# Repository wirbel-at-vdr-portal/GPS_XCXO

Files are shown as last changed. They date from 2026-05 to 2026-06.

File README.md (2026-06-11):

# About
Project goal is a small budget hobbyists GPS disciplined 10MHz XCXO with less than 0.01Hz freq offset at 10MHz using a GPS receiver with 1PPS output.

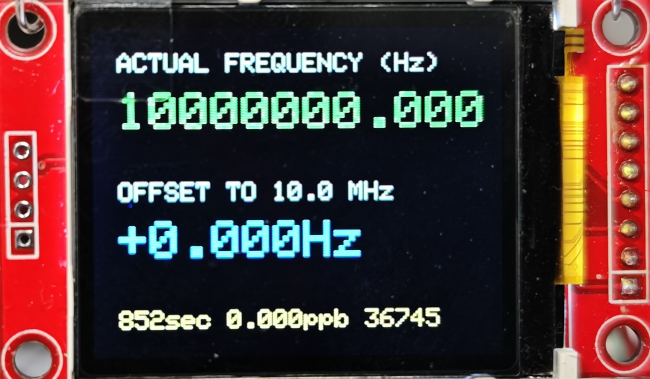
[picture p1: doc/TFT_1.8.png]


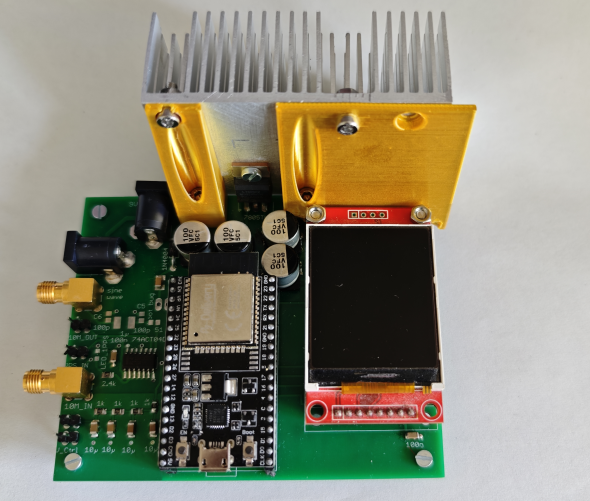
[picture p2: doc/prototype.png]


# Ingredients
- an cheap 10MHz OCXO with 0..4 volts V_control input, which has in it's voltage control range the center freq of 10.000000 MHz and CMOS or TTL output,
  costs at common market places ~15€. I use an CTI OSC5A2B02 OCXO based board. It needs to be modified however, to have a control voltage input instead of a potentiometer.
- an ESP32 devkit C V4, ~12€ (mine was ~8€)
- Arduino IDE with a few libs, 0€, but some efforts in/plus time/research.
- a GPS module with an 1 pulse per second output, in my case
  - Sparkfun GPS-17285 module (Neo-M9N)
  - Sparkfun GPS-14986 antenna
- a few electronic components
- an old 1.8 inch TFT based on St7735, i use the one with the large SD card slot, ~6€
- the PCB, design is here, ~25€ for 5 pieces.
- a 9..12volts DC power supply with ~1amp continously, - no costs. Everybody has such one laying around. Preferred with the 5.5mm 'DC connector', plus is inner.

# How it is working
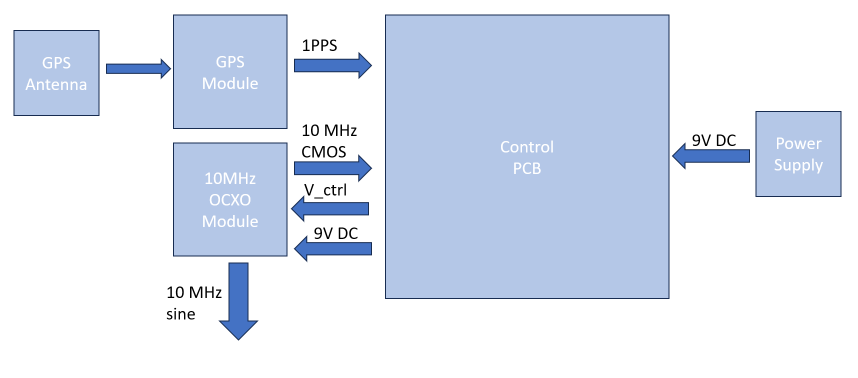
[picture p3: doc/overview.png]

- the 1PPS signal from the GNSS / GPS module triggers an interrupt routine, which resets a counter.
- the 10MHz signal is counted by the ESP32 specific hardware counter PCNT. Every 30000 counts, this counter fires a second ISR to count it's overflows.
  This ISR is called 333 times a second.
- if the gate time is over, we remember the current counter value (0..29999) as 'last_counter' and calculate the number of pulses: pulses = current_counter + overflows * 30000 - last_counter
- now, we can calculate the frequency: frequency = pulses / gate_time
- and the current frequency error in ppb: errorPPB = (measuredFreq - TARGET_FREQ) / (TARGET_FREQ / 1e9)
- as our OCXO is voltage controlled by 0..4volts, we need to generate a control voltage. We generate a 16-bit PWM, again using hardware counters of the ESP32.
- the pwm signal is RC filtered, we need to put a bit effort in this filter. We want more than 120dB frequency suppression for the PWM frequency.
- and finally, we somehow need to map an error in ppb to an PWM value. This job serves a digital filter with a bit brain, the Kalman filter.
- if the OCXO is learned, the program stores from time to time the current state

# Modification of the OCXO board
My OCXO board doesnt have a control voltage input. Instead, the input is wired to a potentiometer. The modified circuit is shown below.

NOTE: the original schematic was not done by me, see doc folder for original.

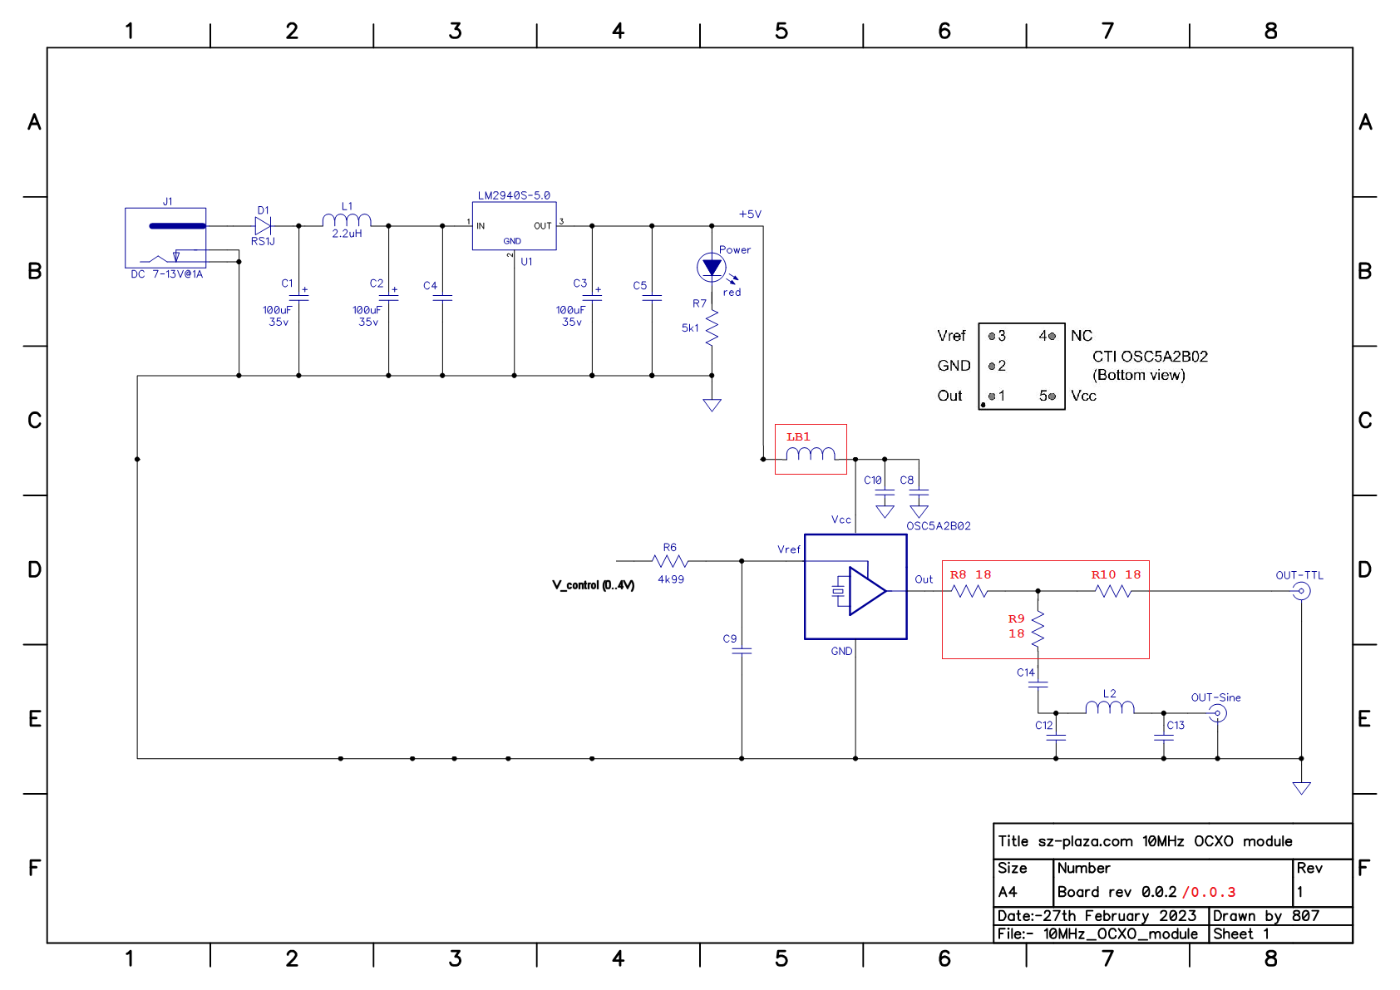
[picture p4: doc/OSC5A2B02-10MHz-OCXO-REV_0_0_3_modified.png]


# Performance
- for my system, which is a very early breadboard-like assembly
- the algorithm needs time to adapt the OCXO, learn it's properties, so it's slow. Don't expect good results in less than two hours.
- there are still plenty of knobs to tune
- we need the OCXO control signal as clean as possible, so shielding and good RC filtering is mandatory.
- TODO
  - improve GPS quality (cheap module)
  - tune code, if GPS loss or invalid values.

| Running hh:mm:ss | abs(FreqOffset), Hz | PWM change 0..65535 | Uncertainty | comment |
| --- | --- | --- | --- | --- |
| 00:00:10 | 2.9 | 4751 | 490.8 | |
| 00:00:20 | 1.8 | 2949 | 947.4 | |
| 00:02:00 | 1.65 | 2703 | 264.0 | |
| 00:03:40 | 0.51 |  836 | 205.7 | |
| 00:12:00 | 0,216 |  354 |  10.7 | |
| 00:28:40 | 0.058 | 95 | 2.65 | |
| 00:45:20 | 0.013 | 21 | 2.31 | |
| 01:02:00 | 0.002 | 3 | 1.9982 | |
| 01:18:40 | 0.040 | 7 | 1.726 | GPS err  |
| 01:18:50 | 0 | 0 | 3.4488 | algo! |
| 01:35:30 | 0.002 | 3 | 1.8489 | recover  |
| 01:52:10 | 0.001 | 2 | 1.3932 | |

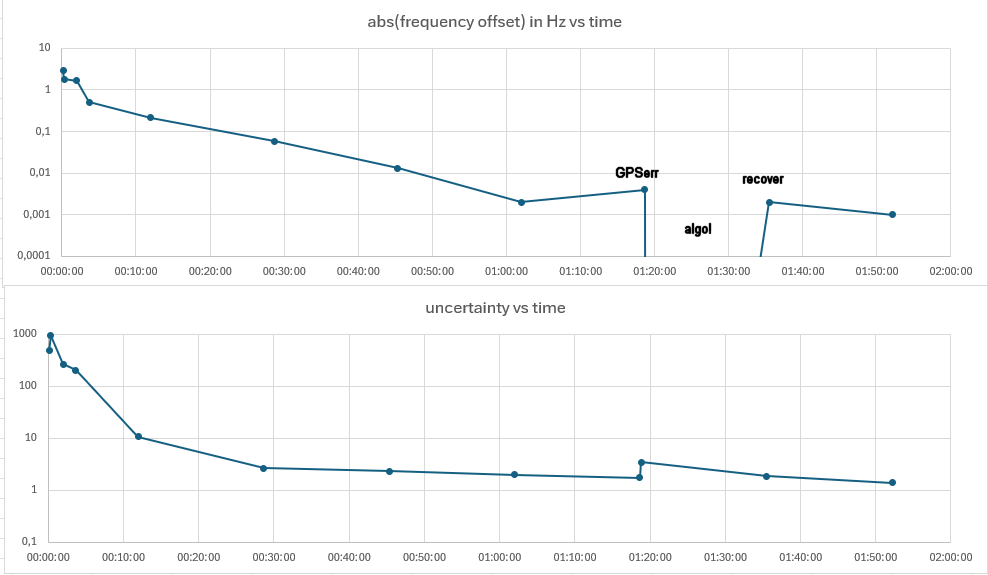
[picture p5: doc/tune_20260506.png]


***NOTE NOTE NOTE:***

***This is work in progress. Everything still changes day by day. Success is optional, this is a fully fun based project.***

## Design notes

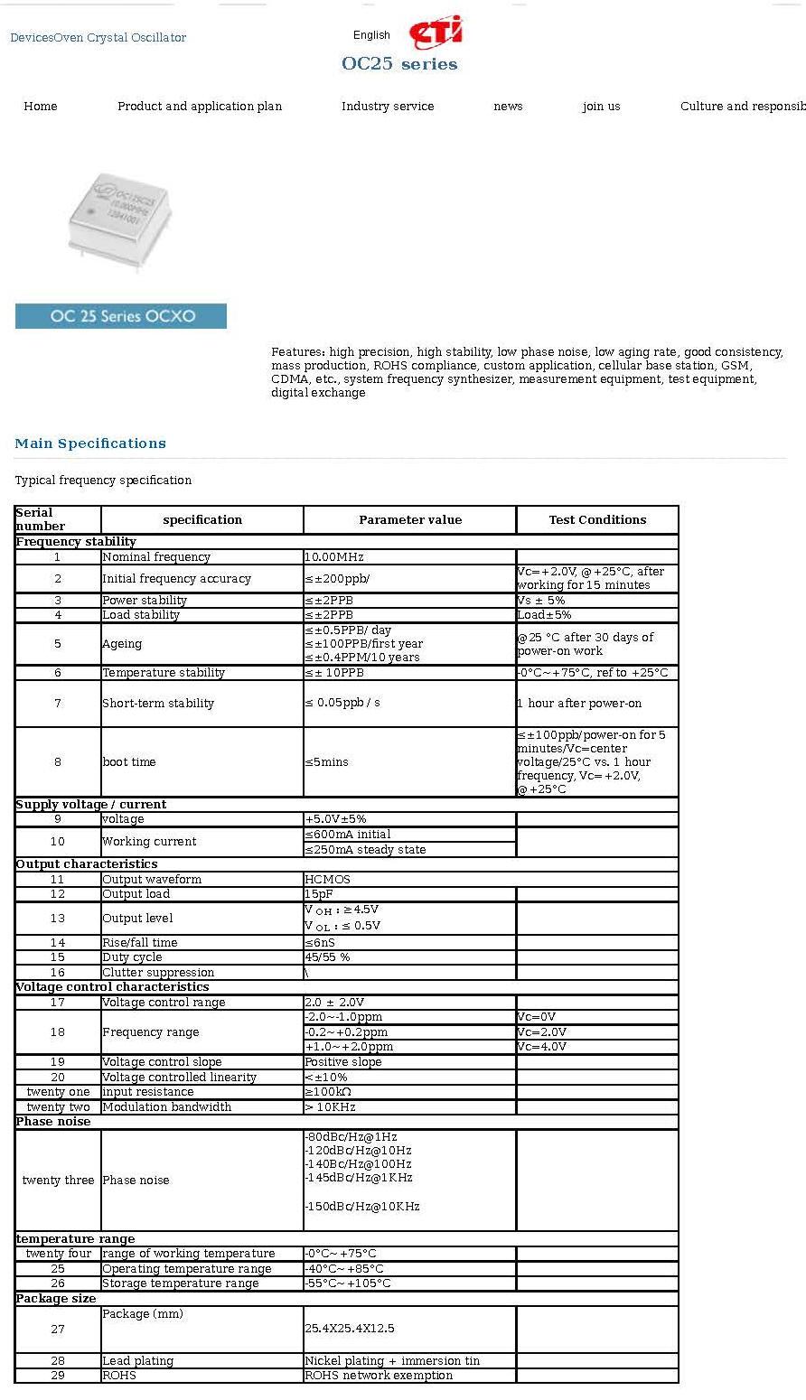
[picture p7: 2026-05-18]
doc/CTI Serie25 VC-OCXO.jpg

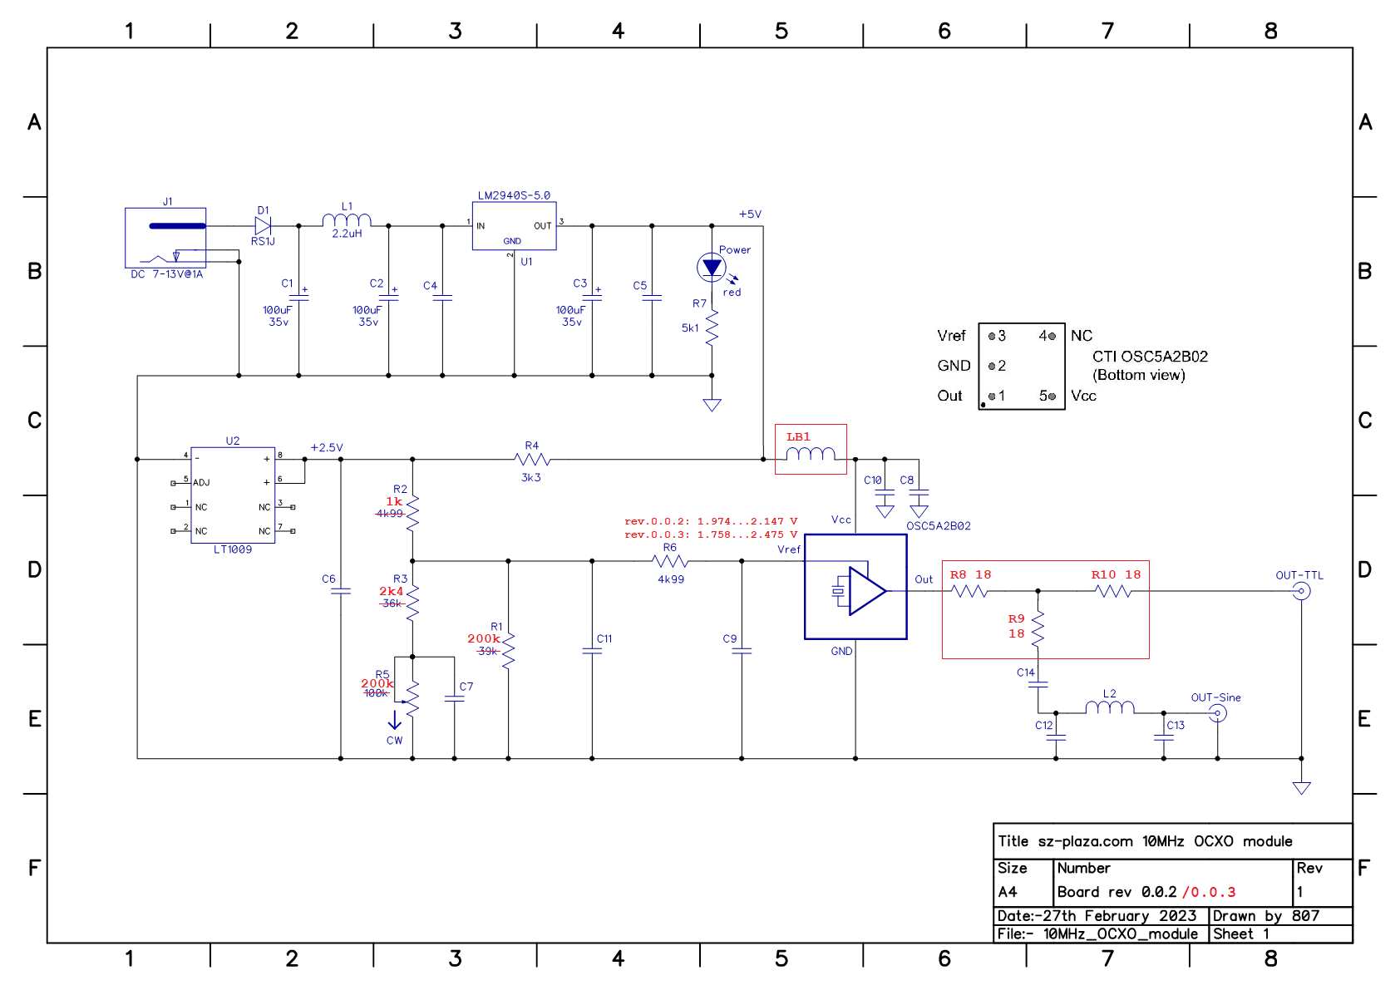
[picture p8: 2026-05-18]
doc/OSC5A2B02-10MHz-OCXO-REV_0_0_3.png

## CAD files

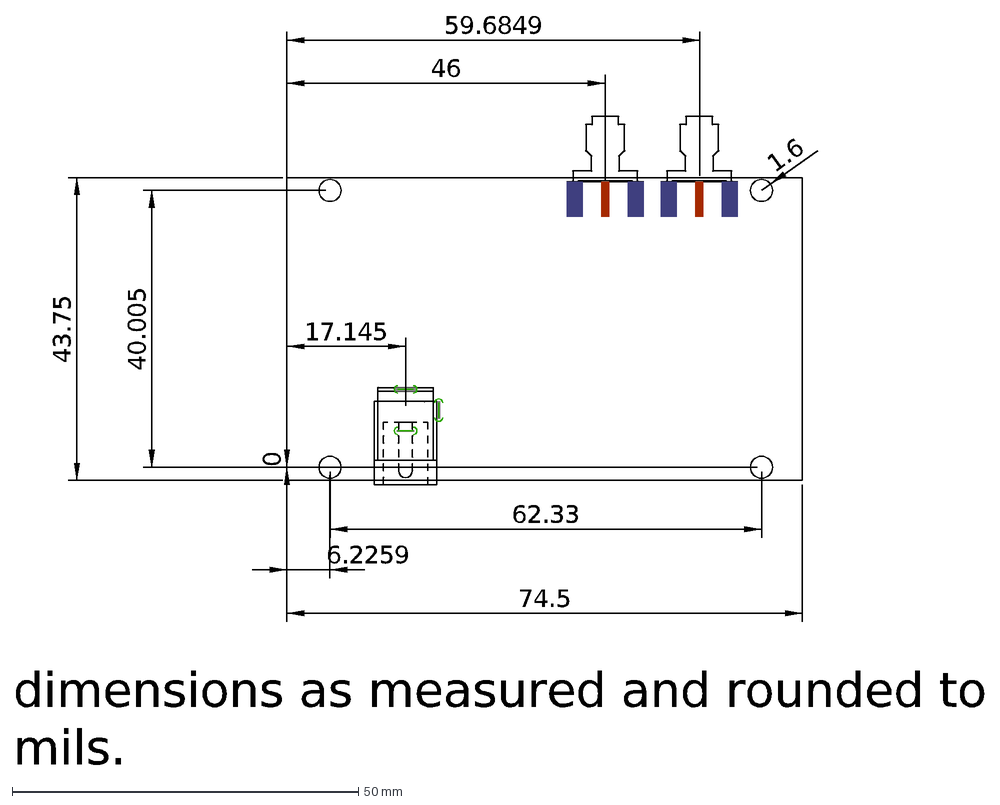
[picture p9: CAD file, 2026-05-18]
doc/OCXO-board-dimensions.dxf
43.75
40.005
62.33
6.2259
0
46
59.6849
74.5
dimensions as measured and rounded to mils.
1.6
17.145

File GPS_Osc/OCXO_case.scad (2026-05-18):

$fn=100;
use <wk/RoundBox.scad>
use <wk/RoundCylinder.scad>


// PCB outer dims.
h=1.6;
t = 43.375;
b = 74.5;

// die Loecher im PCB
t1 = 40.005;
d = 3.2;
b1 = 6.2259;
b2 = 62.33;
  
  
  
module PCB() {
  t1 = 40.005;
  d = 3.2;
  b1 = 6.2259;
  b2 = 62.33;
  
  color("Green") 
  difference() {
     translate([0,0,h/2]) cube([b,t,h], true);
     translate([-b/2+b1,-t1/2,-0.5]) cylinder(5, d=d);
     translate([-b/2+b1,+t1/2,-0.5]) cylinder(5, d=d);
     translate([-b/2+b1+b2,-t1/2,-0.5]) cylinder(5, d=d);
     translate([-b/2+b1+b2,+t1/2,-0.5]) cylinder(5, d=d);
     }
}

module DC005() {
  color("Grey") 

  difference() {
    union() {
      translate([-3.3/2,0,11/2]) RoundBox(3.3,9,11, 0.5);
      translate([-14.2/2,0,6.5/2]) RoundBox(14.2,9,6.5, 0.5);     
      translate([-14.2,0,(9-1)/2+2]) rotate([0,90,0]) RoundCylinder(h=14.2, d=9-1, 0.5);
      }
    translate([-8,0,6.5]) rotate([0,90,0]) RoundCylinder(h=10, d=6.4, 0.5);
    } 
  color("Silver") translate([-9,0,6.5]) rotate([0,90,0]) RoundCylinder(h=8, d=2.5, 0.25);  


}

module SMA_female() {
  color("Gold")
  difference() {
     union() {
        translate([13.5-4-8    ,0, +0.8/2]) rotate([0,90,0]) RoundCylinder(h=8, d=5.3, 0.1);
        translate([13.5-4-8+(4.3-1.7),0, +0.8/2]) rotate([0,90,0]) RoundCylinder(h=5, d=6.35, 0.3);
        
        translate([+1.5/2,0, +0.8/2]) rotate([0,90,0]) RoundBox(6.5,6.5,1.5, 0.07);
        
        translate([-4/2,+(6-0.9)/2, +0.8/2]) rotate([0,90,0]) RoundBox(0.9,0.9,4.0, 0.07);
        translate([-4/2,-(6-0.9)/2, +0.8/2]) rotate([0,90,0]) RoundBox(0.9,0.9,4.0, 0.07);
        translate([-4/2,+(6-0.9)/2, +0.8/2-(1.7+0.9)]) rotate([0,90,0]) RoundBox(0.9,0.9,4.0, 0.07);
        translate([-4/2,-(6-0.9)/2, +0.8/2-(1.7+0.9)]) rotate([0,90,0]) RoundBox(0.9,0.9,4.0, 0.07);
        }
     translate([13.5-4-8+1,0, +0.8/2]) rotate([0,90,0]) RoundCylinder(h=8, d=4.65, 0.1);
     translate([13.5-4-8-1.6,0, +0.8/2]) rotate([0,90,0]) RoundCylinder(h=8, d=4, 0.1);
     }

  difference() {
     union() {
        color("White") translate([13.5-4-8-1.5,0, +0.8/2]) rotate([0,90,0]) RoundCylinder(h=2, d=4, 0.1);
        color("White") translate([13.5-4-8-0  ,0, +0.8/2]) rotate([0,90,0]) RoundCylinder(h=6, d=4.65, 0.1);
        }
     color("Gold") translate([13.5-4-8-1.6,0, +0.8/2]) rotate([0,90,0]) RoundCylinder(h=10, d=1, 0.1);
     }
  color("Gold") translate([-4,0, +0.8/2]) rotate([0,90,0]) RoundCylinder(h=10, d=1, 0.1);
}

module OCXO() {
  color("Silver")
  union() {
     translate([0,0,12.5/2]) RoundBox(23.65,23.65, 12.5, 1.5);
     translate([0,0,0.8/2]) RoundBox(25.2,25.2, 0.8, 0.1);  
     }
}

module OCXO_module() {
  PCB();
  translate([-b/2+17.145,-t/2-1,h]) rotate([0,0,-90]) DC005();
  translate([-b/2+46,+t/2,h]) rotate([0,0,+90])       SMA_female();
  translate([-b/2+59.6849,+t/2,h]) rotate([0,0,+90])  SMA_female();
  
  translate([-b/2+41.68+23.65/2,-t/2+3.04+23.65/2,h]) OCXO();
  
}


//OCXO_module();





module Rohr(h, di, da) {
  
  difference() {
     cylinder(h, d=da);
     translate([0,0,-1]) cylinder(h+2, d=di);  
     }

}


module case() {
  // 4x Halter
  translate([-b/2+b1,-t1/2   ,-10]) Rohr(10, 2.6, 2.6+2*2);
  translate([-b/2+b1,+t1/2   ,-10]) Rohr(10, 2.6, 2.6+2*2);
  translate([-b/2+b1+b2,-t1/2,-10]) Rohr(10, 2.6, 2.6+2*2);
  translate([-b/2+b1+b2,+t1/2,-10]) Rohr(10, 2.6, 2.6+2*2);
 
  // Boden
  spalt=1.5;
  difference() {
     translate([0,0,-10-4/2]) RoundBox(b+2*4+2*spalt, t+2*4+2*spalt, 4, 0.5);
     // 4x loch fuer halter. Vereinfacht gewinde schneiden.     
     translate([-b/2+b1,-t1/2   ,-12.5]) cylinder(10, d=2.6);
     translate([-b/2+b1,+t1/2   ,-12.5]) cylinder(10, d=2.6);
     translate([-b/2+b1+b2,-t1/2,-12.5]) cylinder(10, d=2.6);
     translate([-b/2+b1+b2,+t1/2,-12.5]) cylinder(10, d=2.6);
     }
  
  // kurze Seiten
  h_box = 4+10+1.6+12.5+6+4; // = 38.1
  difference() {
     union() {
        translate([+b/2+4/2+spalt,0,-10-4+h_box/2]) RoundBox(4, t+2*4+2*spalt, h_box, 0.5);
        translate([-b/2-4/2-spalt,0,-10-4+h_box/2]) RoundBox(4, t+2*4+2*spalt, h_box, 0.5);
        }
     translate([-50,+17.5,20]) rotate([0,+90,0]) cylinder(100, d=3.2); 
     translate([-50,-17.5,20]) rotate([0,+90,0]) cylinder(100, d=3.2);
     }

  // lange Seiten
  difference() { // SMA Seite
    translate([0,+t/2+4/2+spalt,-10-4+h_box/2]) RoundBox(b+2*4+2*spalt, 4, h_box, 0.5);
    translate([-b/2+46     ,+t/2+1.5,h]) rotate([-90,0,0]) RoundCylinder(10, 10.5, 2);    
    translate([-b/2+59.6849,+t/2+1.5,h]) rotate([-90,0,0]) RoundCylinder(10, 10.5, 2);    
    translate([-b/2+46     ,+t/2-3.2,h+6]) rotate([0,0,0]) RoundBox(11,11,22, 1);
    translate([-b/2+59.6849,+t/2-3.2,h+6]) rotate([0,0,0]) RoundBox(11,11,22, 1);    
    translate([-b/2+70,+t/2,h+5]) rotate([-90,0,0]) cylinder(10, d=5); // 1PPS
    }

  difference() { // power Seite
    translate([0,-t/2-4/2-spalt,-10-4+h_box/2]) RoundBox(b+2*4+2*spalt, 4, h_box, 0.5);
    translate([-b/2+17.145,-t/2+3,h+9])    rotate([0,0,-90]) RoundBox(11,11,22, 1);
    translate([-b/2+17.145,-t/2-1.8,h+6.5]) rotate([+90,0,0]) RoundCylinder(10, 10.5, 2);  
    }
}

module deckel() {
  // Deckel
  spalt=1.5;
  h_box = 4+10+1.6+12.5+6+4;
  translate([0,0,1.6+12.5+6+4+4/2]) RoundBox(b+2*4+2*spalt, t+2*4+2*spalt, 4, 0.5);
  difference() {
     union() {
        translate([+b/2-4/2+spalt,0,-10-8+h_box]) RoundBox(4, t-1+2*spalt, 10, 0.5);
        translate([-b/2+4/2-spalt,0,-10-8+h_box]) RoundBox(4, t-1+2*spalt, 10, 0.5);
        }
     translate([-50,+17.5,20]) rotate([0,+90,0]) cylinder(100, d=2.5); 
     translate([-50,-17.5,20]) rotate([0,+90,0]) cylinder(100, d=2.5);
     }
}

color("Aqua") case();
deckel();

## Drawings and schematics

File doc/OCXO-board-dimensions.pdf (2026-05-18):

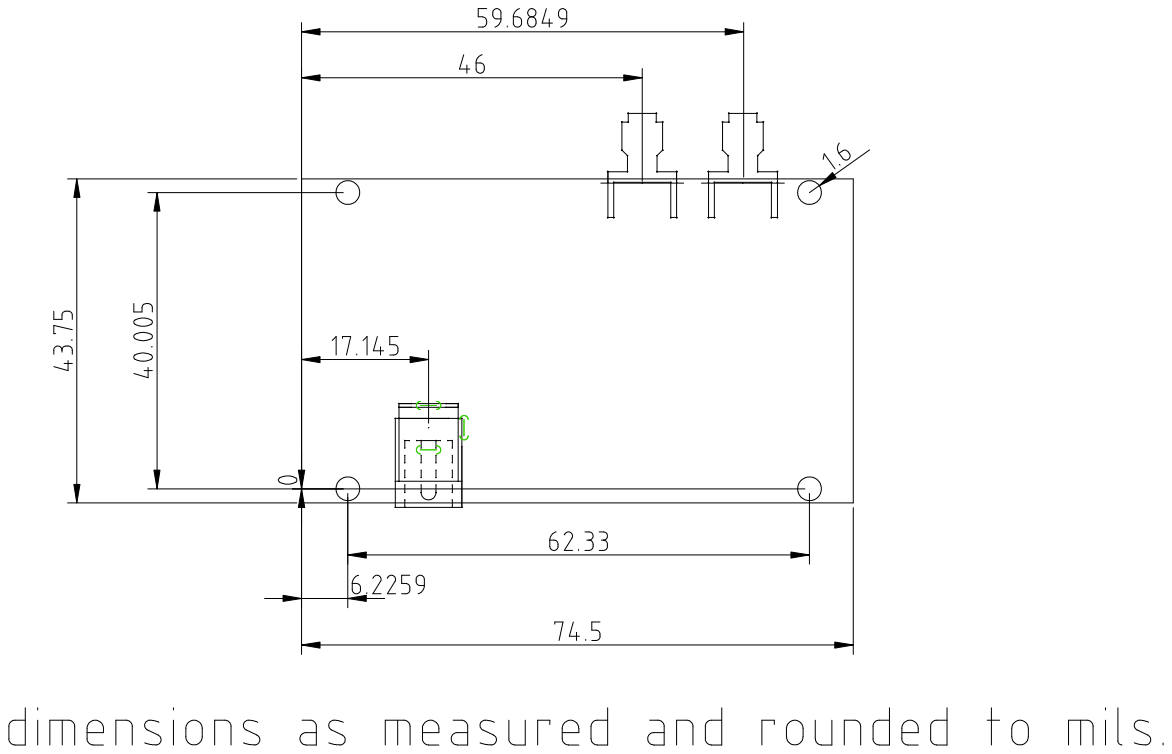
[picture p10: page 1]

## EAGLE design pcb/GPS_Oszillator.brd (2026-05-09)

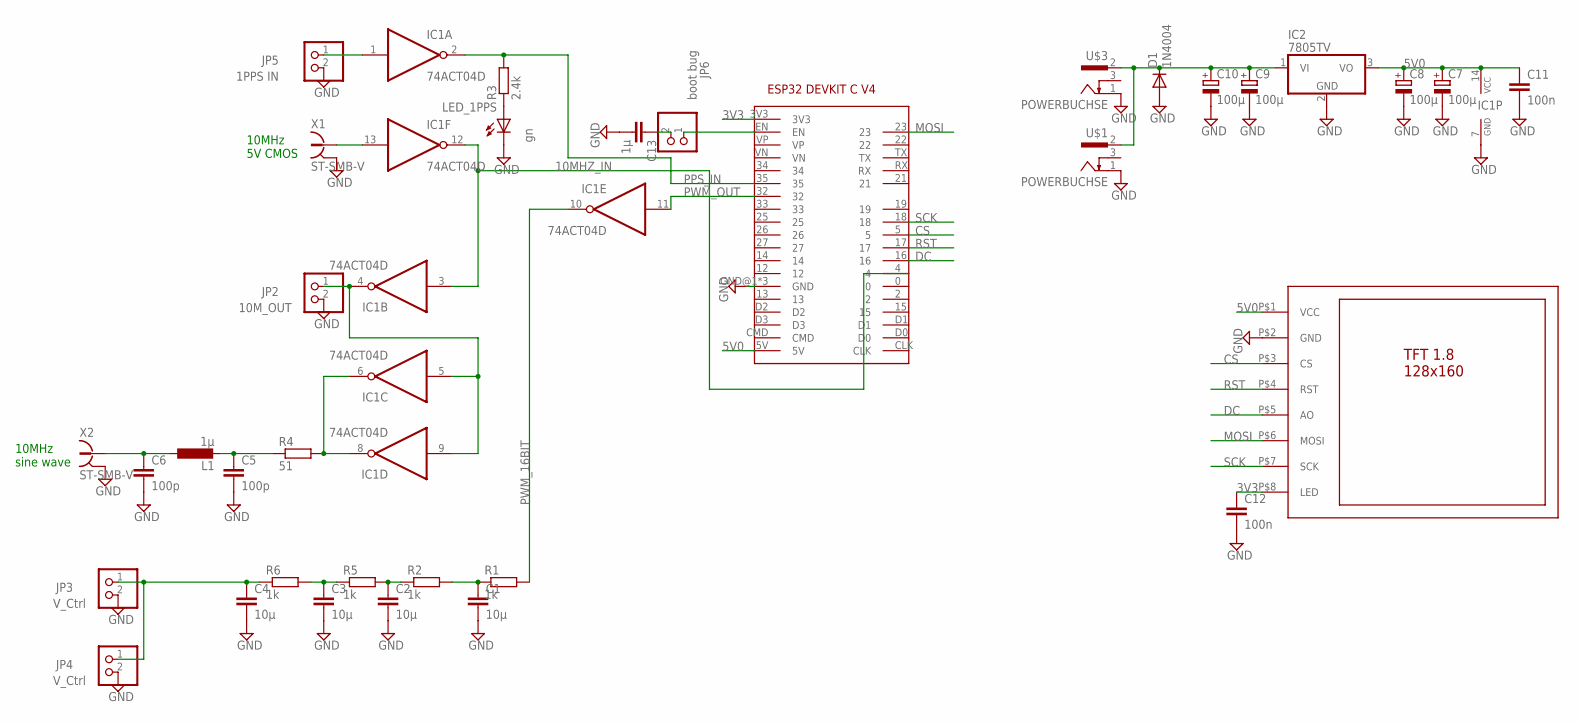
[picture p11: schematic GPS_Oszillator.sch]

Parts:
C1, C2, C3, C4: 10µ; C1206
C5, C6: 100p; C0805
C7, C8, C9, C10: 100µ; SANYO-OSCON_SMD_E7
C11, C12: 100n; C0805
C13: 1µ; C1210
D1: 1N4004; DO41-10
IC1: 74ACT04D; SO14
IC2: 7805TV; TO220V
JP2: 10M_OUT; 1X02
JP3, JP4: V_Ctrl; 1X02
JP5: 1PPS IN; 1X02
JP6: boot bug; 1X02
L1: 1µ; L1812
LED_1PPS: gn; CHIPLED_0805
R1, R2, R5, R6: 1k; R0805
R3: 2.4k; R0805
R4: 51; R0805
U$1, U$3: POWERBUCHSE
U$2: TFT_18
U$4: ESP32_DEVKITC_V4; ESP32_DEVKIT_C_V4
X1, X2: ST-SMB-V

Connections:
3V3: C12.1, U$2.P$8 (LED), U$4.3V3
5V0: C7.+, C8.+, C11.1, IC1.14 (VCC), IC2.3 (VO), U$2.P$1 (VCC), U$4.5V
10MHZ_IN: IC1.3 (I), IC1.12 (O), U$4.4
CS: U$2.P$3 (CS), U$4.5
DC: U$2.P$5 (AO), U$4.16
ESP32_EN: JP6.1, U$4.EN
GND: C1.2, C2.2, C3.2, C4.2, C5.2, C6.2, C7.-, C8.-, C9.-, C10.-, C11.2, C12.2, C13.2, D1.A, IC1.7 (GND), IC2.2 (GND), JP2.2, JP3.2, JP4.2, JP5.2, LED_1PPS.C, U$1.1 (2), U$2.P$2 (GND), U$3.1 (2), U$4.GND@1 (GND), U$4.GND@2 (GND), U$4.GND@3 (GND), X1.2, X1.3 (2), X1.4 (2), X1.5 (2), X2.2, X2.3 (2), X2.4 (2), X2.5 (2)
MOSI: U$2.P$6 (MOSI), U$4.23
unnamed: C3.1, R5.1, R6.2
unnamed: IC1.4 (O), IC1.5 (I), IC1.9 (I), JP2.1
unnamed: C2.1, R2.1, R5.2
unnamed: C13.1, JP6.2
unnamed: C1.1, R1.1, R2.2
unnamed: C4.1, JP3.1, JP4.1, R6.1
unnamed: IC1.1 (I), JP5.1
unnamed: LED_1PPS.A, R3.1
unnamed: C6.1, L1.1, X2.1
unnamed: C5.1, L1.2, R4.1
unnamed: IC1.6 (O), IC1.8 (O), R4.2
unnamed: C9.+, C10.+, D1.C, IC2.1 (VI), U$1.2 (1), U$3.2 (1)
unnamed: IC1.13 (I), X1.1
PPS_IN: IC1.2 (O), R3.2, U$4.35
PWM_16BIT: IC1.10 (O), R1.2
PWM_OUT: IC1.11 (I), U$4.32
RST: U$2.P$4 (RST), U$4.17
SCK: U$2.P$7 (SCK), U$4.18

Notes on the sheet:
10MHz 5V CMOS
10MHz sine wave

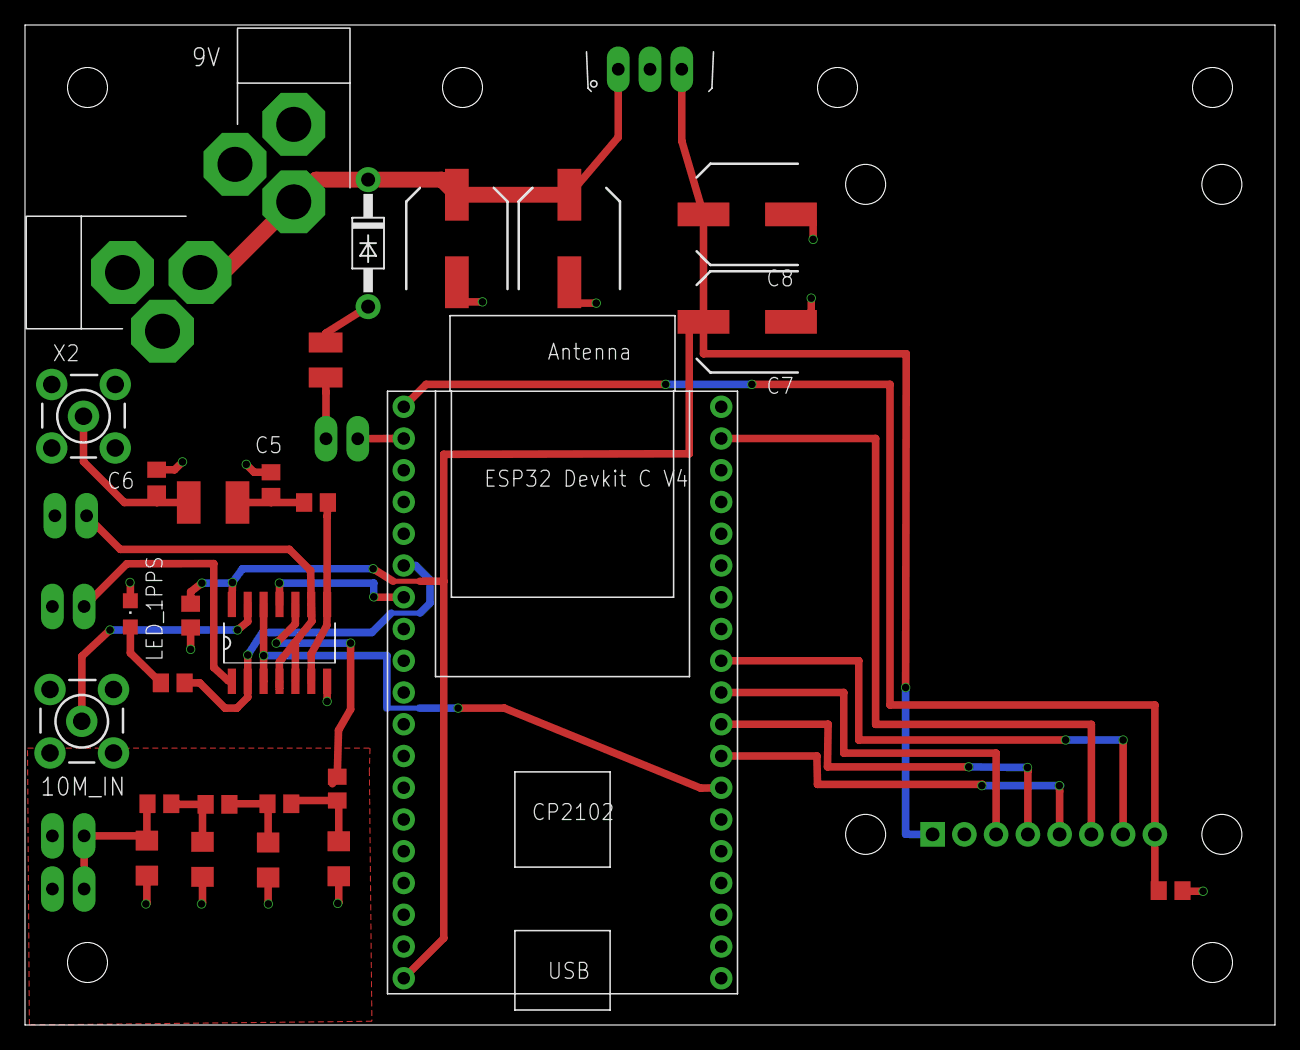
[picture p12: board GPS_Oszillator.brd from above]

Board: 2 copper layers, 100.0 x 80.0 mm, 35 parts (0 on the bottom side), 26 nets.

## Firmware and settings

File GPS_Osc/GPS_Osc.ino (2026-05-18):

/*******************************************************************************
 * Project Page: https://github.com/wirbel-at-vdr-portal/GPS_XCXO
 ******************************************************************************/
#include <Arduino.h>
#include <stdint.h>           // uint16_t, uint32_t
#include <atomic>
#include <SPI.h>              // SPI(MOSI,SCK,SS) for ST7735 1.8 TFT display
#include <Adafruit_GFX.h>     // display
#include <Adafruit_ST7735.h>  // display
#include "driver/pulse_cnt.h" // PCNT is a 16bit hardware counter on ESP32
#include "hal/pcnt_ll.h"      // pcnt_ll_get_count()
#include "Kalman_Filter.h"
#include "esp32-hal-cpu.h"
#include <Preferences.h>      // https://docs.espressif.com/projects/arduino-esp32/en/latest/tutorials/preferences.html

// generic macros
#define kHz(f) 1000ULL * (unsigned long long)f
#define MHz(f) 1000ULL * kHz(f)
#define ARRAY_SIZE(a)  ( sizeof(a)/sizeof(a[0]) )
#define IN_RANGE(X, MINIMUM, MAXIMUM) (   ( (X) >= (MINIMUM) ) && ( (X) <= (MAXIMUM) )    )


/* In the Arduino IDE, configure this board:
 * "ESP32 Arduino -> ESP32 Dev Module"
 *
 * Now, let's declare the pins we used on the PCB.
 *
 * NOTE: GPIO 34,35,36,39 are input only and doent have internal pullup
 *       resistors -> avoid those pins for the PCNT counter, as they
 *       throw a runtime error regarding the pullup config. 
 */
#define SS      5  // slave select, or, chip select
#define DC      16 // data/command (DC), labeled 'AO' on TFT
#define RST     17 // tft reset (-1 for Arduino RESET pin doesnt work..)
//      MOSI    23
//      MISO    19
//      SCK     18
#define PPS_IN  35 // 1Hz signal from GPS, pin 35 supports hardware PCNT counter.
#define OSC_IN   4 // 10MHz CMOS signal from OCXO
#define PWM_OUT 32 // 16bit PWM
#define FREQUENCY      MHz(10)
uint64_t MAX_COUNTER = 30000; // less or equal 32767

pcnt_unit_handle_t pcnt_unit = NULL;
Preferences esp32_flash;

// our 1.8 ST7735 based TFT, connected to hw  SPI
Adafruit_ST7735 Display = Adafruit_ST7735(SS, DC, RST);


/* grouping all ISR related variables increases the chance, that our compiler
 * can optimise our code better by using short jumps on access.
 */
struct ISR_Data {
  int32_t ticks;       // set in OnPPS
  uint32_t Overflows;  // increased in OnOverflow, reset in OnPPS
  uint32_t overflows;  // increased in OnOverflow, reset in OnPPS
  int32_t count;       // set in OnPPS
  uint32_t ready;      // set in OnPPS
  uint32_t isr_duration;  // debug only.
} __attribute__((aligned(4)));

volatile ISR_Data isr_data = {10, 0, 0, 0, 0, 0};



int gate_time = 10;                  // time for smoothing, up to 100, may be later larger.
uint32_t pwm_val;                    // PWM freq < (80*1000*1000)/2^Resolution; 1220Hz for 16bit.
uint32_t pwm_frequency = 1220;



// ISR: triggered every MAX_COUNTER counts by PCNT
static bool IRAM_ATTR OnOverflow(pcnt_unit_handle_t unit, const pcnt_watch_event_data_t* edata, void* user_ctx) {
  isr_data.Overflows = isr_data.Overflows + 1; // warning on ++ operator
  return false; // no context switch.
}

// ISR: triggered every 1.0000000 Hz
void IRAM_ATTR OnPPS() {
  isr_data.count = pcnt_ll_get_count(PCNT_LL_GET_HW(0), 0);

  isr_data.ticks = isr_data.ticks - 1; // warning on -- operator
  if (isr_data.ticks > 0) return;

  isr_data.overflows = isr_data.Overflows;
  isr_data.Overflows = 0;
  isr_data.ticks = 1000000; // actually disabled. will be updated by loop()
  isr_data.ready = 1;
}

void setup(void) {
  uint32_t currentFreq = getCpuFrequencyMhz();
  if (currentFreq != 240) {
     setCpuFrequencyMhz(240);
     }

  Serial.begin(115200);
  delay(1000);

  Display.initR(INITR_BLACKTAB);    // Init ST7735S chip, black tab
  Display.fillScreen(ST77XX_BLACK);
  Display.setTextColor(ST77XX_WHITE);
  Display.setRotation(1);
  Display.setTextSize(2);
  Display.setCursor(10, 25);
  Display.setTextColor(ST77XX_GREEN, ST77XX_BLACK);
  Display.println("Waiting..");

  pinMode(OSC_IN, INPUT);
  pinMode(PPS_IN, INPUT);
  pinMode(PWM_OUT, OUTPUT);


  /* setup PCNT 16-bit hardware counter
   * NOTES:
   * 1. The counter value is signed (-32768..32767). Therefore,
   *    MAX_COUNTER <= 32767.
   * 2. The PCNT noise filter runs on 80MHz, one clk is 12.5nsec;
   *    for 10MHz the high period should be ~50nsec at 50 duty cycle.
   *    Setting the filter higher than 4 will definitly loose all
   *    counts, values less than 2 should be resonable.
   * 3. This is the newer version of the PCNT api.
   */

  pcnt_unit_config_t unit_config = {
     .low_limit = -1,
     .high_limit = (int16_t)MAX_COUNTER,
     //.flags = { .accum_count = true },
     .intr_priority = 3, // max ISR prio for C/C++
     };
  pcnt_new_unit(&unit_config, &pcnt_unit);
  pcnt_glitch_filter_config_t filter_config = {.max_glitch_ns = 13,}; // 13nsec. 1/80MHz = 12.5nsec
  pcnt_unit_set_glitch_filter(pcnt_unit, &filter_config);
  pcnt_chan_config_t chan_config = {.edge_gpio_num = OSC_IN, .level_gpio_num = -1,};
  pcnt_channel_handle_t pcnt_chan = NULL;
  pcnt_new_channel(pcnt_unit, &chan_config, &pcnt_chan);
  pcnt_channel_set_edge_action(pcnt_chan,
     PCNT_CHANNEL_EDGE_ACTION_INCREASE, // on rising edge increase
     PCNT_CHANNEL_EDGE_ACTION_HOLD);    // on falling edge no action.
  pcnt_event_callbacks_t cbs = { .on_reach = OnOverflow,};
  pcnt_unit_register_event_callbacks(pcnt_unit, &cbs, NULL);
  pcnt_unit_add_watch_point(pcnt_unit, (int)MAX_COUNTER);
  pcnt_unit_enable(pcnt_unit);
  pcnt_unit_clear_count(pcnt_unit);
  pcnt_unit_start(pcnt_unit);

  // enable 1Hz ISR
  attachInterrupt(PPS_IN, OnPPS, RISING);

  esp32_flash.begin("Kalman", false);
  state.x_pwm           = esp32_flash.getDouble("x_pwm"  , 32768.0);
  state.x_drift         = esp32_flash.getDouble("x_drift", 0.0    );
  state.P00             = esp32_flash.getDouble("P00"    , 100.0  );
  state.P01 = state.P10 = esp32_flash.getDouble("P01"    , 0.0    );
  state.P11             = esp32_flash.getDouble("P11"    , 1.0    );
  last_state = state;
  pwm_val = (uint32_t) constrain(state.x_pwm + 0.5, 0, 65535);

  if (not(ledcAttach(PWM_OUT, pwm_frequency, 16)))
     Serial.println("ledcAttach failed.");
  else {
     pwm_frequency = ledcReadFreq(PWM_OUT);
     Serial.print("PWM started, freq = "); Serial.println(pwm_frequency);
     ledcWrite(PWM_OUT, 65535 - pwm_val);
     }
}


uint64_t pulses = 0;
uint64_t last_count; // if we store here the last count value, we dont need to reset the PCNT
double frequency;
double last_frequency;
double offset;
double offset_ppb;
int last_ticks = 10;
int timeout = 0;
uint32_t overflows32, count32;

double last_freqs[4];
bool last_valid[4];


portMUX_TYPE myMux = portMUX_INITIALIZER_UNLOCKED;

void loop() {

  if (isr_data.ready == 1) {

     portENTER_CRITICAL(&myMux);    // earlier: noInterrupts();
     count32     = isr_data.count;
     overflows32 = isr_data.overflows;
     isr_data.ready = 0;
     portEXIT_CRITICAL(&myMux);     // earlier: interrupts();


     pulses = overflows32 * MAX_COUNTER + count32; // MAX_COUNTER is uint64_t
     pulses -= last_count; // we did not start at zero anymore.
     last_count = count32;

     // we take up to (gate_time) secs samples and average
     last_frequency = frequency;
     frequency = ((double) pulses) / gate_time;
     offset = frequency - FREQUENCY;


     last_freqs[3] = last_freqs[2]; last_valid[3] = last_valid[2];
     last_freqs[2] = last_freqs[1]; last_valid[2] = last_valid[1];
     last_freqs[1] = last_freqs[0]; last_valid[1] = last_valid[0];
     last_freqs[0] = frequency;     last_valid[0] = (fabs(offset) < 0.003) and (gate_time >= 1000);

     double samples = 1.0;
     if (last_valid[0]) {
        if (last_valid[1]) {
           frequency += last_freqs[1];
           samples = 2.0;
           if (last_valid[2]) {
              frequency += last_freqs[2];
              samples = 3.0;
              if (last_valid[3]) {
                 frequency += last_freqs[3];
                 samples = 4.0;
                 }
              }
           frequency /= samples;
           offset = frequency - FREQUENCY;
           }
        }
      /* Note: we need to call the filter, even if the freq is fully off.
       *       The filter checks the freq to be valid.
       */
     pwm_val = kalman_filter(frequency, gate_time);
     offset_ppb = (frequency - FREQUENCY) / (FREQUENCY / 1e9);

     ledcWrite(PWM_OUT, 65535 - pwm_val);

     if (fabs(offset) > 20.0) {
        Display.setTextSize(1);
        Display.setCursor(10, 10);
        Display.setTextColor(ST77XX_WHITE, ST77XX_BLACK);
        Display.println("ACTUAL FREQUENCY (Hz)");
        Display.setTextSize(2);
        Display.setCursor(10, 25);
        Display.setTextColor(ST77XX_RED, ST77XX_BLACK);
        Display.print(last_frequency, 3); 
        Display.print("              ");
        Serial.print("gate_time:"); Serial.print(gate_time); Serial.println(",");
        Serial.print("isr_data.ticks:"); Serial.print(isr_data.ticks); Serial.println(",");
        Serial.print("count32:"); Serial.print(count32); Serial.println(",");
        Serial.print("overflows32:"); Serial.print(overflows32); Serial.println(",");
        Serial.print("frequency:"); Serial.print(frequency,3); Serial.println(" - Bad Freq !!");
        isr_data.ticks = gate_time;
        return;
        }

     Serial.print("pulses:"); Serial.print(pulses); Serial.print(",");

     if ((fabs(offset) < 0.1) and (fabs(state.x_pwm - last_state.x_pwm) > 1.0)) {
        Serial.println("saving state..");
        last_state = state;
        esp32_flash.putDouble("x_pwm", state.x_pwm);
        esp32_flash.putDouble("x_drift", state.x_drift);
        esp32_flash.putDouble("P00", state.P00);
        esp32_flash.putDouble("P01", state.P01);
        esp32_flash.putDouble("P11", state.P11);
        }

     // --- TFT output ---
     Display.setRotation(1); // 1 = 160x128 (Landscape)
     Display.setTextWrap(false); // Verhindert Zeilenumbruch bei Überlänge

     // 1. frequency
     Display.setTextSize(1);
     Display.setCursor(10, 10);
     Display.setTextColor(ST77XX_WHITE, ST77XX_BLACK);
     Display.println("ACTUAL FREQUENCY (Hz)");
     Display.setTextSize(2);
     Display.setCursor(10, 25);
     Display.setTextColor(ST77XX_GREEN, ST77XX_BLACK);
     Display.print(frequency, 3); 
     Display.print("              ");

     // 2. offset
     Display.setTextSize(1);
     Display.setCursor(10, 60);
     Display.setTextColor(ST77XX_WHITE, ST77XX_BLACK);
     Display.println("OFFSET TO 10.0 MHz");
     Display.setTextSize(2);
     Display.setCursor(10, 75);
     Display.setTextColor((abs(offset) < 1.0) ? ST77XX_CYAN : ST77XX_RED, ST77XX_BLACK);   
     if (offset >= 0) Display.print("+");
     Display.print(offset, 4);
     Display.print("Hz      ");


          if (abs(offset) > 2.0)    gate_time = 10;
     else if (abs(offset) >= 1.0)   gate_time = 100;
     else if (abs(offset) >= 0.3)   gate_time = 500;
     else                           gate_time = 1000;
     isr_data.ticks = gate_time;


     // 3. status bar
     Display.setTextSize(1);
     Display.setCursor(10, 110);
     Display.setTextColor(ST77XX_YELLOW, ST77XX_BLACK);
     if (gate_time < 10) Display.print(" ");
     Display.print(gate_time); Display.print("sec ");
     Display.print(offset_ppb,3); Display.print("ppb ");
     Display.print(pwm_val); Display.print("            ");
     }
  else {
     if (last_ticks != isr_data.ticks) {
        last_ticks = isr_data.ticks;
        Display.setRotation(1);
        Display.setTextWrap(false); // Verhindert Zeilenumbruch bei Überlänge
        Display.setTextSize(1);
        Display.setCursor(10, 110);
        Display.setTextColor(ST77XX_YELLOW, ST77XX_BLACK);
        if (gate_time < 10) Display.print(" ");
        Display.print(isr_data.ticks+1); Display.print("sec ");
        Display.print(offset_ppb,3); Display.print("ppb ");
        Display.print(pwm_val); Display.print("            ");
        timeout = 0;
        }
     else
        timeout++;
     if (timeout % 100 > 95) {
        Display.setRotation(1);
        Display.fillScreen(ST77XX_BLACK);
        Display.setTextSize(2);
        Display.setCursor(10, 25);
        Display.setTextColor(ST77XX_RED, ST77XX_BLACK);
        Display.println("No Reference");
        }
     }
  delay(100);
}



/* to count cpu clocks, we have a xtal counter available:
uint32_t start = xthal_get_ccount();
uint32_t end   = xthal_get_ccount();
isr_duration = end - start;
*/

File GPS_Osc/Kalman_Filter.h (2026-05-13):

/*******************************************************************************
 * Project Page: https://github.com/wirbel-at-vdr-portal/GPS_XCXO
 ******************************************************************************/
#include <Arduino.h>


/* NOTES:
 *------------------------------------------------------------------------------
 * 0. Before reading this source code, be shure to read about the
 *    'Kalman filter', for example:
 *       - https://en.wikipedia.org/wiki/Kalman_filter
 *    Only after that, continue.
 *
 *
 *    From the link above..
 *    [cite]
 *     "This Kalman filtering was first described and developed partially in
 *      technical papers by Swerling (1958), Kalman (1960) and Kalman and Bucy
 *      (1961).
 *      The Apollo computer used 2k of magnetic core RAM and 36k wire rope [...].
 *      The CPU was built from ICs [...]. Clock speed was under 100 kHz [...]. The
 *      fact that the MIT engineers were able to pack such good software (one of
 *      the very first applications of the Kalman filter) into such a tiny
 *      computer is truly remarkable.
 *         Interview with Jack Crenshaw, by Matthew Reed, TRS-80.org (2009) [1]"
 *    [/cite]
 *------------------------------------------------------------------------------
 *
 * 1. State coupling: Through P01 and P10, the filter "knows" that an error
 *    in the frequency could also be due to an incorrectly estimated drift.
 *
 * 2. Holdover intelligence: If GPS fails (ppsValid = false), the filter
 *    only calculates the "predict" part. Since x_drift was learned during
 *    good times, your OCXO continues to run much more precisely than with
 *    a simple fixed value.
 *
 * 3. Adaptation to dt: Since the Variance R becomes extremely small at
 *    measuring time dt=100, the filter almost perfectly replicates the
 *    measurement. At dt=1, however, it massively "smooths" across the matrix.
 *
 * 4. A small practical tip: Before you activate the system, let it run for
 *    about 10-20 minutes at dt=1 so that the matrix P can decrease from its
 *    high initial values to stable operating values.
 *
 * 5. In Kalman filter theory, S stands for innovation covariance (also called
 *    system uncertainty). I use the variable name 'total_uncertainty'.
 *    It can be simplified as the total uncertainty present at the moment
 *    of measurement.
 *    It consists of two parts:
 *        P00 (estimation error): How uncertain is the filter about its own
 *                                state (x_pwm)?
 *        the variance 'R', or measurement noise: How much does the current
 *                          GPS measurement fluctuate?
 *    Why is S so important? The variable S forms the denominator in the
 *    calculation of the Kalman gain (K).
 *       K = P/S = (own uncertainty) / (own uncertainty + measurement noise)
 *
 *    This gives the logic of the filter:
 *    - If our measurement noise (R) is huge compared to your own uncertainty (P), S becomes very large.
 *      This results in a tiny K. The filter says, "The measurement is so noisy, I'll almost completely
 *      ignore it."
 *    - If your own uncertainty (P) is very large (e.g., right after starting) and the measurement is clean,
 *      K approaches 1. The filter says, "I have no idea where I am; I trust the measurement completely."
 *
 *    - In summary, S is the measure of the combined uncertainty, which the filter uses to decide how much
 *      weight to give to the new measurement compared to its previous prediction.
 *
 *    - Variance (P00, P11): The square of the standard deviation.
 *                           A high value means "I'm just guessing," a small value means "I'm very sure."
 *
 *    - Correlation (P01, P10): These values link the two states.
 *                              They allow the filter to say, "If the frequency continues to deviate upwards,
 *                              I probably need to adjust my drift estimate."
 *
 *    - Innovation: The difference between what the filter predicted and what the GPS actually
 *                  measured (the "surprise effect").
 *
 *    - Observe the variable `state.x_drift`.
 *         Does it drift steadily towards a small value (e.g., 0.000123)?
 *           -> Yes. Your filter is learning the aging perfectly.
 *           -> No.  Does it jump around wildly? Then either your `Q_drift` is too high or
 *                   the `DEADZONE_PWM` is still too small for your current measurement
 *                   interval `dt`.
 *
 */




struct KalmanGPSDO {
  // --- States ---
  double x_pwm;      // Estimated optimal PWM value (0 - 65535)
  double x_drift;    // Estimated drift rate (PWM change per second)

  // --- Covariance Matrix P (System Uncertainty) ---
  // P represents the estimation error.
  // The diagonal elements (P00, P11) are the variances of our states.
  double P00;        // Estimation error variance for PWM value
  double P01;        // Correlation between PWM error and Drift error
  double P10;        // (Symmetric to P01)
  double P11;        // Estimation error variance for the Drift rate

  // --- Process Noise Q (OCXO Stability) ---
  // Q defines how much uncertainty we add per second.
  double Q_pwm;      // Random walk of the OCXO frequency. 1e-4 (bad stability) .. 1e-9 (ultra precise, but slow)
  double Q_drift;    // Instability of the aging/drift rate 1e-6 (warming up) .. 1e-10 (thermal not disturbed)

  double innovation; // how large our last step was.
  bool ppsValid;
};


KalmanGPSDO state = {
  .x_pwm   = 32768.0,         // middle of 16-bit PWM range.
  .x_drift = 0.0,             // no freq drift
  .P00     = 100.0,           // Estimation error variance for PWM value
  .P01     = 0.0, .P10 = 0.0, // Correlation between PWM error and Drift error. Symmetric.
  .P11     = 1.0,             // Estimation error variance for the Drift rate
  .Q_pwm   = 1e-6,            // 1e-4 (bad stability) .. 1e-9 (ultra precise, but slow)
  .Q_drift = 1e-6,            // 1e-6 (warming up) .. 1e-10 (thermal not disturbed)
  .innovation = 0.0f,         // how large our last step was.
  .ppsValid = false,
};

KalmanGPSDO last_state;



/* Our measure uncertainty is about 3 counts (0.3ppm). For one sec measurement time that
 * means 3Hz. If we increase the measurement time to 10Hz, we get 0.3Hz. And finally,
 * for 100sec 0.03Hz. This is the uncertainty in PWM bits:
 */
const double TARGET_FREQ = 10000000.0;
const double PWM_PRO_PPM = 65535.0 / 4.0; 
const double MEASUREMENT_ERROR_PWM = 0.1 * PWM_PRO_PPM; // 1 count error at 1s; ~1638
const double MAX_DRIFT = 0.00007;
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

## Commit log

2026-04-30 Change PWM filter
    [GPS_Oszillator.brd, GPS_Oszillator.sch]
2026-05-02 Add first version of an Kalman Filter
    A Kalman filter is an iterative mathematical algorithm used to optimally estimate the state of a dynamic system (such as position or velocity) from a series of measurement errors. It was introduced by Rudolf E. Kálmán in 1960 and is now a standard tool in robotics, navigation, and signal processing. How it works: The filter operates recursively in a closed loop consisting of two main phases: Prediction: Based on a mathematical model (e.g., equations of motion), the next state of the system and its uncertainty are predicted. In this step, the uncertainty usually increases (process noise). Correction (Update): As soon as a new measurement (e.g., GPS data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
    [GPS_Osc.ino, Kalman_Filter.h]
2026-05-02 Update PWM generation description in README
2026-05-02 update esp32 inputs.
    [GPS_Oszillator.brd, GPS_Oszillator.sch]
2026-05-03 add second power connector and sort out drc errors
    [GPS_Oszillator.brd, GPS_Oszillator.sch]
2026-05-04 add filter comparison in LTspice
2026-05-04 fix PCNT initialization and dont reset PCNT
    1. fix new initialization of PCNT Driver (v5.x) -> .low_limit = -1
    2. dont reset interrupt in OnOverflow(), just count.
    3. dont reset PCNT to zero in OnPPS() anymore. Instead, remember it's start value in loop(). This increases the counter accuracy.
    4. clean code.
    [GPS_Osc.ino]
2026-05-04 Increase accuracy of filter
    1. use double, instead of float in Kalman filter.
    2. begin playing with tuning variables
    3. add 1000sec measurement time
2026-05-05 save current setup.
2026-05-06 save current state
2026-05-08 Update project goal
    Updated project goal to specify a frequency offset of less than 0.01Hz instead of 0.5Hz.
2026-05-08 update README
    Added note about storing the current state of the OCXO.
2026-05-09 Fix reversed DC Jacks
    [GPS_Oszillator.brd, GPS_Oszillator.sch]
2026-05-09 Increase diameter for inner pole of SMA connector.
    [GPS_Oszillator.brd, GPS_Oszillator.sch]
2026-05-10 Add prototype image to README
    Added a prototype image to the README.
2026-05-12 adopt pwm to inverter gate
2026-06-11 Add OCXO board modification details to README
    Added section on modification of the OCXO board, including a note about the original schematic and an image of the modified circuit.
2026-06-11 sort files
    [GPS_Oszillator.brd, GPS_Oszillator.sch]
